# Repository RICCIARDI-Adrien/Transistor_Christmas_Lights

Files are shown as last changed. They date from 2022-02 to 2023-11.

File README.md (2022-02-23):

# Transistor Christmas Lights

A really simple blinking Christmas lights using only bipolar transistors for its logic.

## Circuits

The board is made of 2 separate circuits : the motherboard and the light.  
The motherboard circuit holds the logic while the light circuit contains the leds.  
The light circuit should be manufactured in about 20 copies.

## Circuit simulation

The circuit concept is simulated with [Logisim Evolution](https://github.com/logisim-evolution/logisim-evolution) version 3.7.2, the Logisim file is located [here](Motherboard/Simulation/Logisim_Simulation.circ).  
I tried to keep the gates count as low as possible and I tried to select gates that also minimize the transistors count.  
The Logicim file gathers some different tests for the same logic block, all these tests are still present in the file if needed.

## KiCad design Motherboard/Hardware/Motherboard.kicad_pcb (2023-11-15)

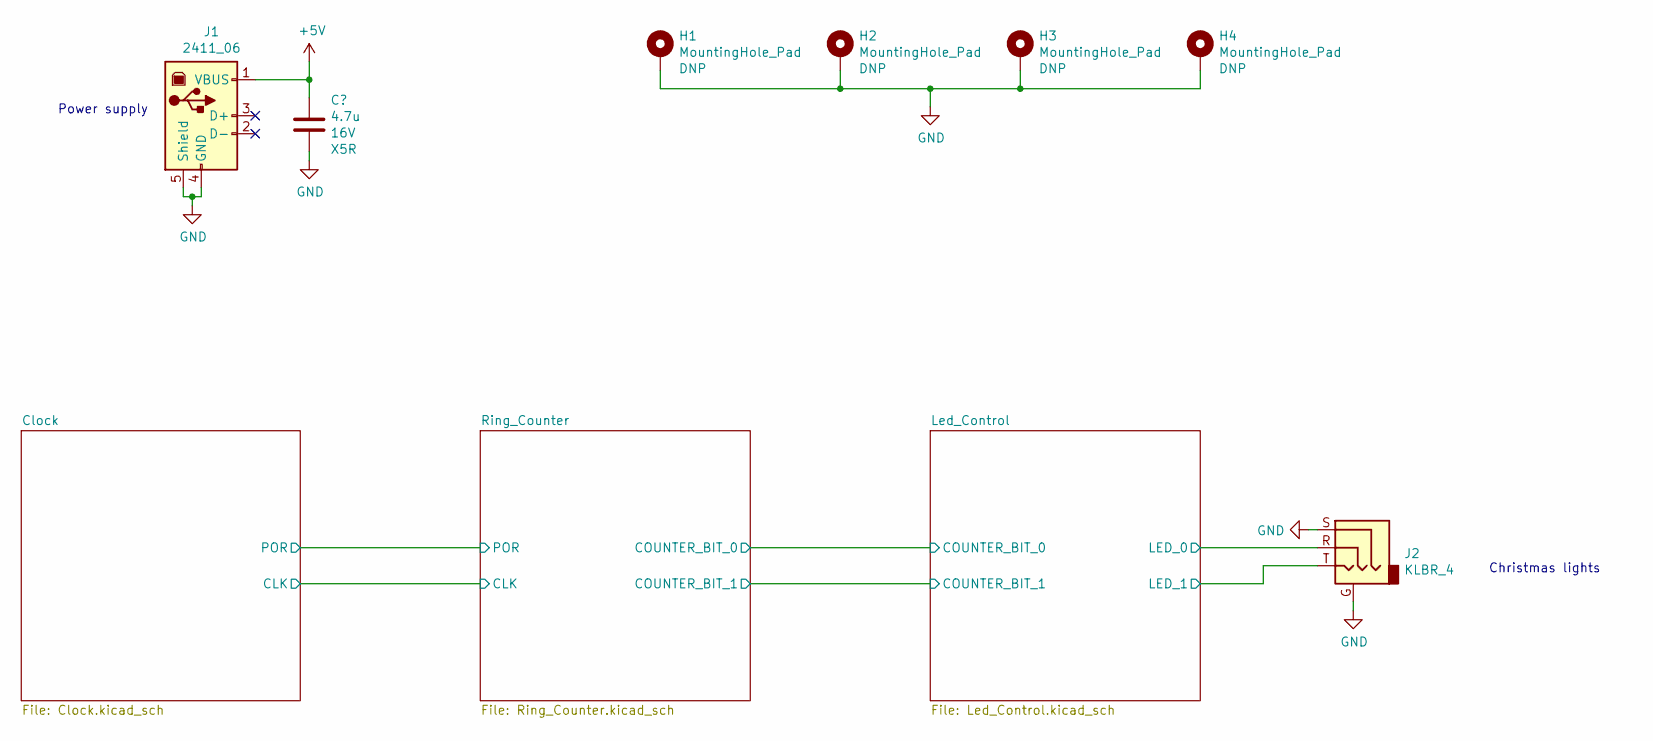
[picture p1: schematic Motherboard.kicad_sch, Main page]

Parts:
C1: 4.7u; C_0805_2012Metric_Pad1.18x1.45mm_HandSolder; PartNumber CL21A475KOFNNNE
H1, H2, H3, H4: MountingHole_Pad; MountingHole_4.5mm_Pad
J1: 2411_06; USB_B_OST_USB-B1HSxx_Horizontal; PartNumber 2411_06
J2: KLBR_4; PartNumber KLBR_4

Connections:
/Led_Control/LED_0: J2.R; also elsewhere on the board
/Led_Control/LED_1: J2.T; also elsewhere on the board
GND: C1.2, H1.1, H2.1, H3.1, H4.1, J1.4 (GND), J1.5 (Shield), J2.G, J2.S; also elsewhere on the board

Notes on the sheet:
Power supply
Christmas lights

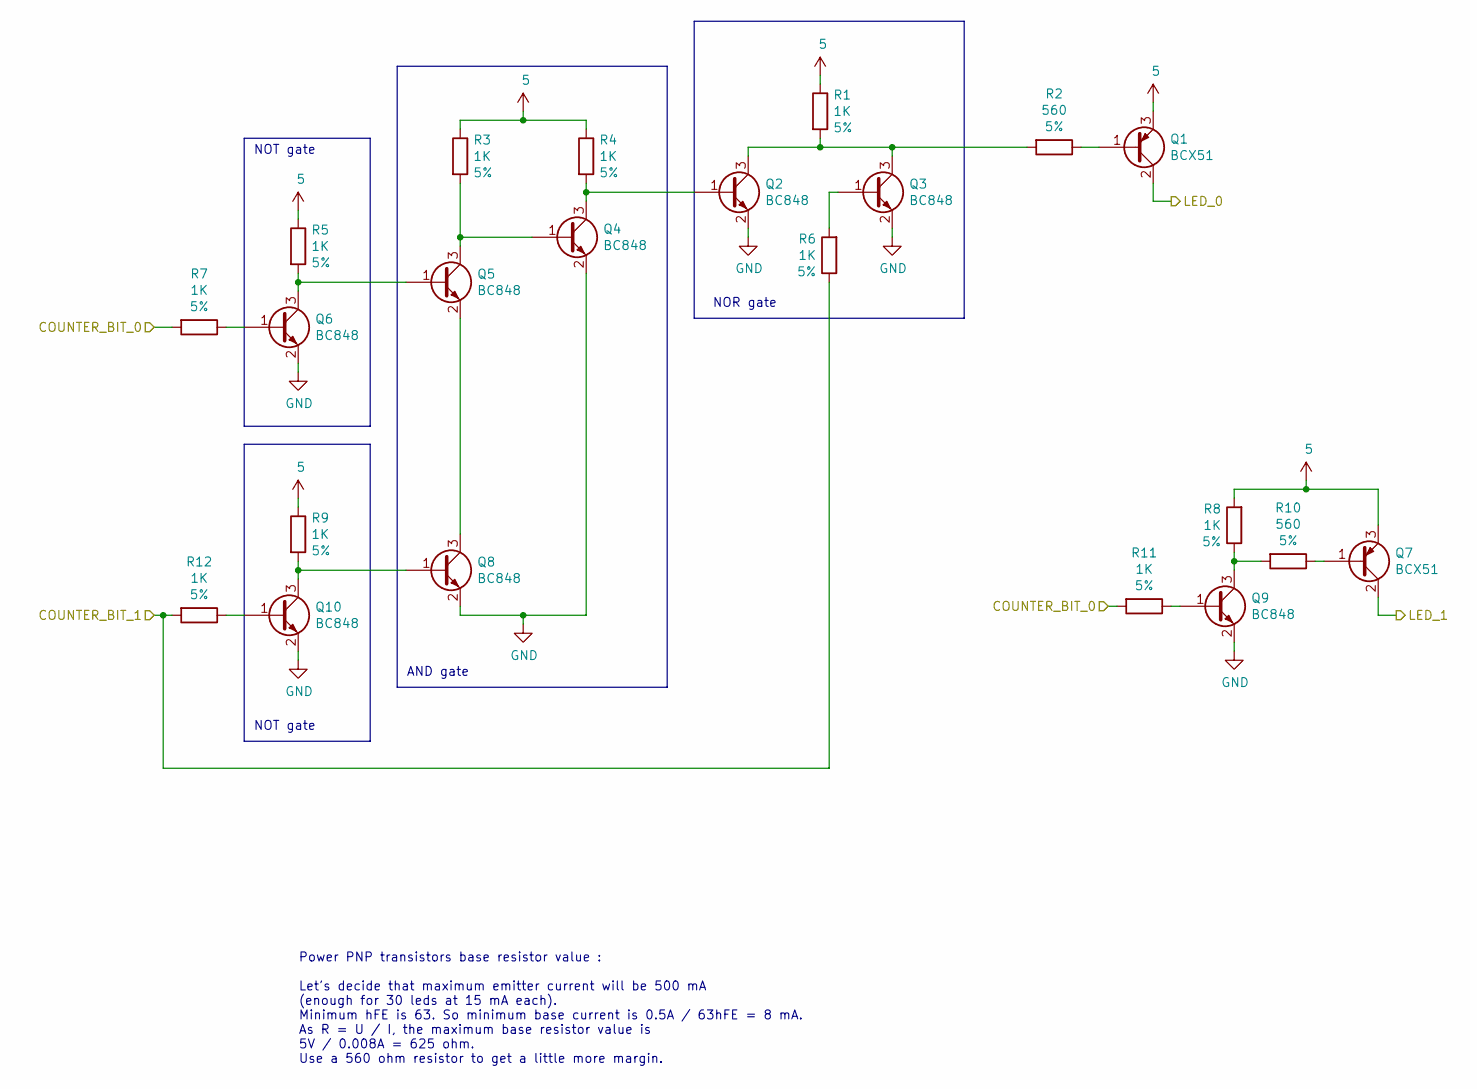
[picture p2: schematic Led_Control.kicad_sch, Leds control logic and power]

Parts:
Q1, Q7: BCX51; SOT-89-3; PartNumber BCX51,115
Q2, Q3, Q4, Q5, Q6, Q8, Q9, Q10: BC848; SOT-23
R1, R3, R4, R5, R6, R7, R8, R9, R11, R12: 1K; R_0603_1608Metric_Pad0.98x0.95mm_HandSolder
R2, R10: 560; R_0603_1608Metric_Pad0.98x0.95mm_HandSolder

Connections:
/Led_Control/COUNTER_BIT_0: R7.2, R11.2; also elsewhere on the board
/Led_Control/COUNTER_BIT_1: R6.1, R12.2; also elsewhere on the board
/Led_Control/LED_0: Q1.2 (C); also elsewhere on the board
/Led_Control/LED_1: Q7.2 (C); also elsewhere on the board
GND: Q2.2 (E), Q3.2 (E), Q4.2 (E), Q6.2 (E), Q8.2 (E), Q9.2 (E), Q10.2 (E); also elsewhere on the board
unnamed: Q1.1 (B), R2.1
unnamed: Q2.1 (B), Q4.3 (C), R4.2
unnamed: Q2.3 (C), Q3.3 (C), R1.2, R2.2
unnamed: Q3.1 (B), R6.2
unnamed: Q4.1 (B), Q5.3 (C), R3.2
unnamed: Q5.1 (B), Q6.3 (C), R5.2
unnamed: Q5.2 (E), Q8.3 (C)
unnamed: Q6.1 (B), R7.1
unnamed: Q7.1 (B), R10.1
unnamed: Q9.1 (B), R11.1
unnamed: Q9.3 (C), R8.1, R10.2
unnamed: Q10.1 (B), R12.1
unnamed: Q8.1 (B), Q10.3 (C), R9.2

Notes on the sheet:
NOT gate
Power PNP transistors base resistor value : Let's decide that maximum emitter current will be 500 mA (enough for 30 leds at 15 mA each). Minimum hFE is 63. So minimum base current is 0.5A / 63hFE = 8 mA. As R = U / I, the maximum base resistor value is 5V / 0.008A = 625 ohm. Use a 560 ohm resistor 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
NOR gate
AND gate

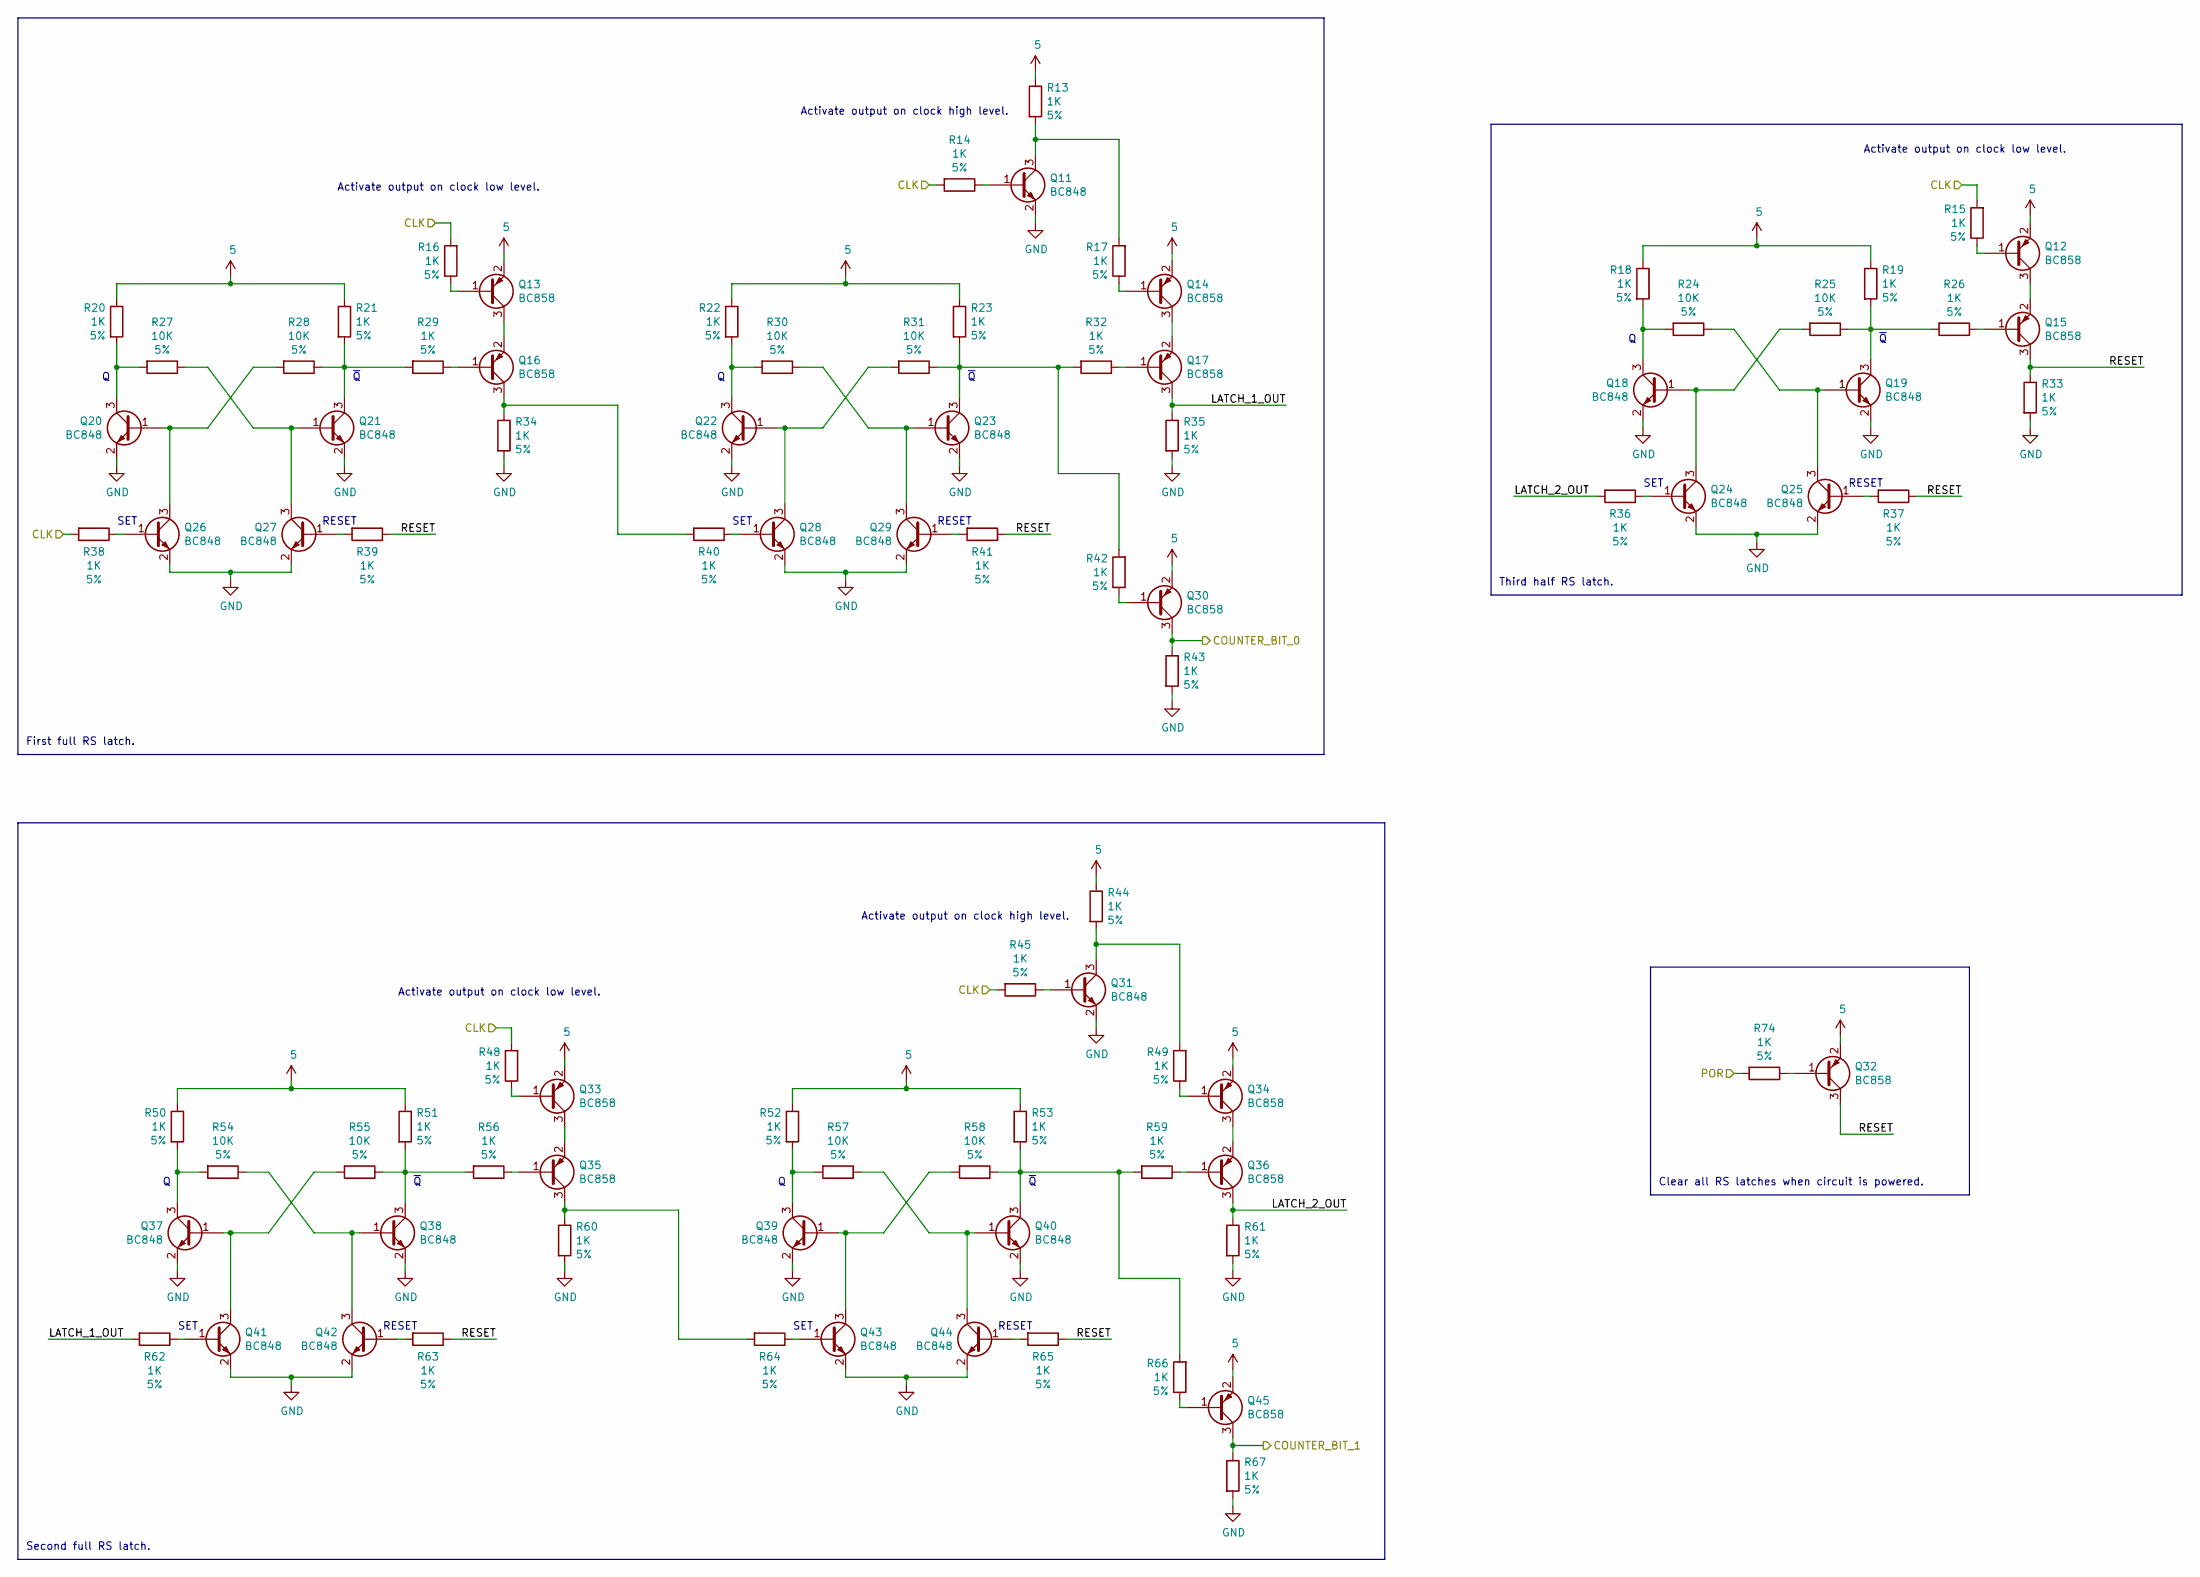
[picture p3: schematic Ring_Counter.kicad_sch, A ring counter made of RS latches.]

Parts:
Q11, Q18, Q19, Q20, Q21, Q22, Q23, Q24, Q25, Q26, Q27, Q28, Q29, Q31, Q37, Q38, Q39, Q40, Q41, Q42, Q43, Q44: BC848; SOT-23
Q12, Q13, Q14, Q15, Q16, Q17, Q30, Q32, Q33, Q34, Q35, Q36, Q45: BC858; SOT-23
R13, R14, R15, R16, R17, R18, R19, R20, R21, R22, R23, R26, R29, R32, R33, R34, R35, R36, R37, R38, R39, R40, R41, R42, R43, R44, R45, R48, R49, R50, R51, R52, R53, R56, R59, R60, R61, R62, R63, R64, R65, R66, R67, R74: 1K; R_0603_1608Metric_Pad0.98x0.95mm_HandSolder
R24, R25, R27, R28, R30, R31, R54, R55, R57, R58: 10K; R_0603_1608Metric_Pad0.98x0.95mm_HandSolder

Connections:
/Clock/CLK: R14.2, R15.2, R16.2, R38.2, R45.2, R48.2; also elsewhere on the board
/Clock/POR: R74.2; also elsewhere on the board
/Led_Control/COUNTER_BIT_0: Q30.3 (C), R43.1; also elsewhere on the board
/Led_Control/COUNTER_BIT_1: Q45.3 (C), R67.1; also elsewhere on the board
/Ring_Counter/LATCH_1_OUT: Q17.3 (C), R35.1, R62.2
/Ring_Counter/LATCH_2_OUT: Q36.3 (C), R36.2, R61.1
/Ring_Counter/RESET: Q15.3 (C), Q32.3 (C), R33.1, R37.1, R39.1, R41.1, R63.1, R65.1
GND: Q11.2 (E), Q18.2 (E), Q19.2 (E), Q20.2 (E), Q21.2 (E), Q22.2 (E), Q23.2 (E), Q24.2 (E), Q25.2 (E), Q26.2 (E), Q27.2 (E), Q28.2 (E), Q29.2 (E), Q31.2 (E), Q37.2 (E), Q38.2 (E), Q39.2 (E), Q40.2 (E), Q41.2 (E), Q42.2 (E), Q43.2 (E), Q44.2 (E), R33.2, R34.2, R35.2, R43.2, R60.2, R61.2, R67.2; also elsewhere on the board
unnamed: Q11.1 (B), R14.1
unnamed: Q11.3 (C), R13.2, R17.2
unnamed: Q12.1 (B), R15.1
unnamed: Q12.3 (C), Q15.2 (E)
unnamed: Q13.1 (B), R16.1
unnamed: Q13.3 (C), Q16.2 (E)
unnamed: Q14.1 (B), R17.1
unnamed: Q14.3 (C), Q17.2 (E)
unnamed: Q15.1 (B), R26.1
unnamed: Q16.1 (B), R29.1
unnamed: Q16.3 (C), R34.1, R40.2
unnamed: Q17.1 (B), R32.1
unnamed: Q18.1 (B), Q24.3 (C), R25.2
unnamed: Q18.3 (C), R18.2, R24.2
unnamed: Q19.1 (B), Q25.3 (C), R24.1
unnamed: Q19.3 (C), R19.2, R25.1, R26.2
unnamed: Q20.1 (B), Q26.3 (C), R28.2
unnamed: Q20.3 (C), R20.2, R27.2
unnamed: Q21.1 (B), Q27.3 (C), R27.1
unnamed: Q21.3 (C), R21.2, R28.1, R29.2
unnamed: Q22.1 (B), Q28.3 (C), R31.2
unnamed: Q22.3 (C), R22.2, R30.2
unnamed: Q23.1 (B), Q29.3 (C), R30.1
unnamed: Q23.3 (C), R23.2, R31.1, R32.2, R42.2
unnamed: Q24.1 (B), R36.1
unnamed: Q25.1 (B), R37.2
unnamed: Q26.1 (B), R38.1
unnamed: Q27.1 (B), R39.2
unnamed: Q28.1 (B), R40.1
unnamed: Q29.1 (B), R41.2
unnamed: Q30.1 (B), R42.1
unnamed: Q31.1 (B), R45.1
unnamed: Q31.3 (C), R44.2, R49.2
unnamed: Q32.1 (B), R74.1
unnamed: Q33.1 (B), R48.1
unnamed: Q33.3 (C), Q35.2 (E)
unnamed: Q34.1 (B), R49.1
unnamed: Q34.3 (C), Q36.2 (E)
unnamed: Q35.1 (B), R56.1
unnamed: Q35.3 (C), R60.1, R64.2
unnamed: Q36.1 (B), R59.1
unnamed: Q37.1 (B), Q41.3 (C), R55.2
unnamed: Q37.3 (C), R50.2, R54.2
unnamed: Q38.1 (B), Q42.3 (C), R54.1
unnamed: Q38.3 (C), R51.2, R55.1, R56.2
unnamed: Q39.1 (B), Q43.3 (C), R58.2
unnamed: Q39.3 (C), R52.2, R57.2
unnamed: Q40.1 (B), Q44.3 (C), R57.1
unnamed: Q40.3 (C), R53.2, R58.1, R59.2, R66.2
unnamed: Q41.1 (B), R62.1
unnamed: Q42.1 (B), R63.2
unnamed: Q43.1 (B), R64.1
unnamed: Q44.1 (B), R65.2
unnamed: Q45.1 (B), R66.1

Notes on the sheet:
Third half RS latch.
SET
~{Q}
RESET
Clear all RS latches when circuit is powered.
Activate output on clock low level.
First full RS latch.
Activate output on clock high level.
Second full RS latch.

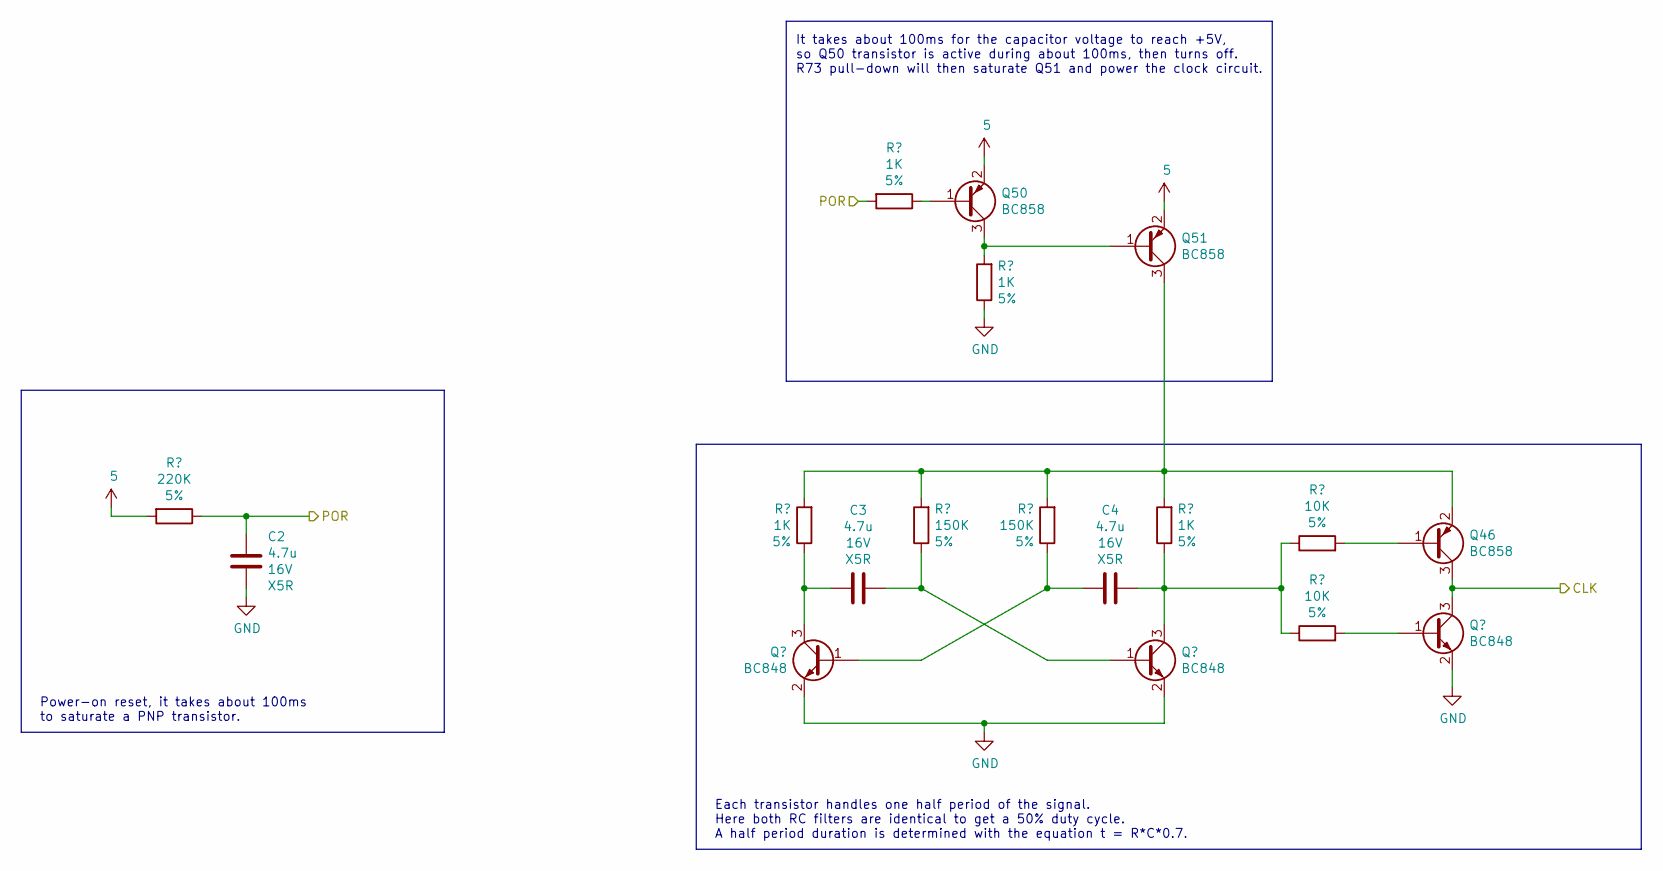
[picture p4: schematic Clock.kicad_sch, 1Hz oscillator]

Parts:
C2, C3, C4: 4.7u; C_0805_2012Metric_Pad1.18x1.45mm_HandSolder; PartNumber CL21A475KOFNNNE
Q46, Q50, Q51: BC858; SOT-23
Q47, Q48, Q49: BC848; SOT-23
R46: 220K; R_0603_1608Metric_Pad0.98x0.95mm_HandSolder
R47, R68, R71, R73: 1K; R_0603_1608Metric_Pad0.98x0.95mm_HandSolder
R69, R70: 150K; R_0603_1608Metric_Pad0.98x0.95mm_HandSolder
R72, R75: 10K; R_0603_1608Metric_Pad0.98x0.95mm_HandSolder

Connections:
/Clock/CLK: Q46.3 (C), Q47.3 (C); also elsewhere on the board
/Clock/POR: C2.1, R46.1, R47.2; also elsewhere on the board
GND: C2.2, Q47.2 (E), Q48.2 (E), Q49.2 (E), R73.1; also elsewhere on the board
unnamed: Q46.1 (B), R72.2
unnamed: Q46.2 (E), Q51.3 (C), R68.2, R69.2, R70.2, R71.2
unnamed: Q47.1 (B), R75.2
unnamed: C4.2, Q48.1 (B), R70.1
unnamed: C3.2, Q48.3 (C), R68.1
unnamed: C3.1, Q49.1 (B), R69.1
unnamed: C4.1, Q49.3 (C), R71.1, R72.1, R75.1
unnamed: Q50.1 (B), R47.1
unnamed: Q50.3 (C), Q51.1 (B), R73.2

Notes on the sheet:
It takes about 100ms for the capacitor voltage to reach +5V, so Q50 transistor is active during about 100ms, then turns off. R73 pull-down will then saturate Q51 and power the clock circuit.
Each transistor handles one half period of the signal. Here both RC filters are identical to get a 50% duty cycle. A half period duration is determined with the equation t = R*C*0.7.
Power-on reset, it takes about 100ms to saturate a PNP transistor.

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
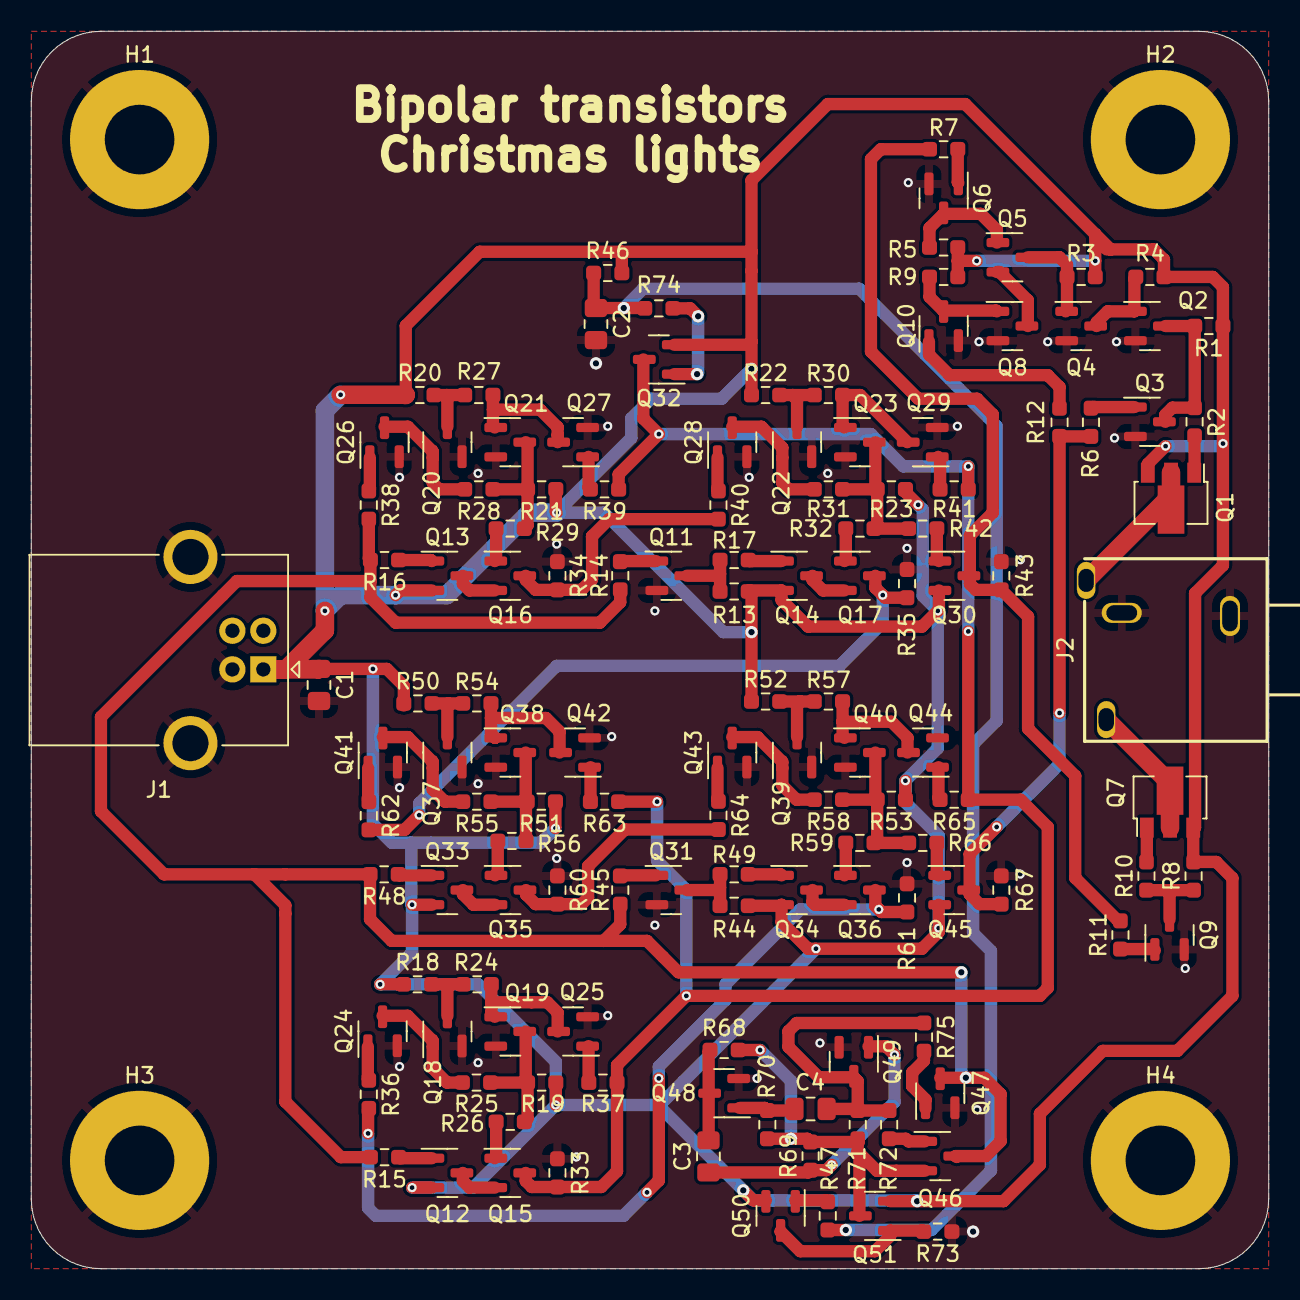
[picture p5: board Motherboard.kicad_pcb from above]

Board: 2 copper layers, 80.0 x 80.0 mm, 136 parts (0 on the bottom side), 87 nets.

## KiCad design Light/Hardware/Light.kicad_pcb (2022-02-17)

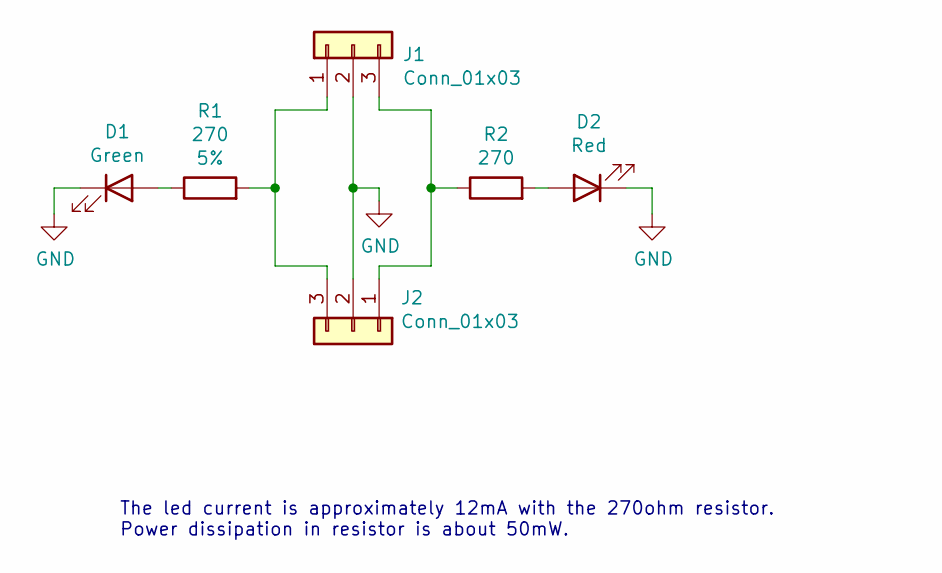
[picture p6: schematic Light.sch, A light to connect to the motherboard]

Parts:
D1: Green; LED_D5.0mm_Horizontal_O1.27mm_Z3.0mm
D2: Red; LED_D5.0mm_Horizontal_O1.27mm_Z3.0mm
J1, J2: Conn_01x03; PinHeader_1x03_P2.54mm_Horizontal
R1, R2: 270; R_1206_3216Metric_Pad1.30x1.75mm_HandSolder

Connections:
GND: D1.1 (K), D2.1 (K), J1.2, J2.2
unnamed: D1.2 (A), R1.1
unnamed: D2.2 (A), R2.2
unnamed: J1.1, J2.3, R1.2
unnamed: J1.3, J2.1, R2.1

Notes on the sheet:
The led current is approximately 12mA with the 270ohm resistor. Power dissipation in resistor is about 50mW.

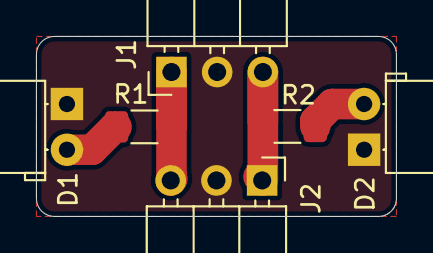
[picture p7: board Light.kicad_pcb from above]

Board: 2 copper layers, 20.0 x 10.0 mm, 6 parts (0 on the bottom side), 5 nets.

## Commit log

2021-12-29 Added a circuit concept simulation based on logic gates.
2021-12-30 Created the PCB KiCad project. Added a test circuit to setup the circuit SPICE simulation.
    [Transistor_Christmas_Lights.kicad_pcb, Transistor_Christmas_Lights.sch]
2022-01-01 Added led control logic to schematic. The second led power transistor will be added later.
    [Led_Control.sch, Transistor_Christmas_Lights.sch]
2022-01-04 Added a ring counter circuit made only of RS latches to the Logicim simulation.
2022-01-04 Removed an unused RS latch in the Logisim ring counter circuit.
2022-01-04 Added the ring counter to the schematic.
    [Led_Control.sch, Ring_Counter.sch, Transistor_Christmas_Lights.sch]
2022-01-20 Improved ring counter RS latches output with better signal quality and less transistors count.
    [Led_Control.sch, Ring_Counter.sch, Transistor_Christmas_Lights.sch]
2022-01-20 Added second led logic and power transistor, also added BC858 SPICE model.
    [Led_Control.sch, Ring_Counter.sch, Transistor_Christmas_Lights.sch]
2022-02-16 Added RS latches power-on reset.
    [Led_Control.sch, Ring_Counter.sch]
2022-02-16 Added oscillator to schematic.
    [Clock.sch, Led_Control.sch, Ring_Counter.sch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]
2022-02-16 Moved motherboard hardware design to a dedicated directory to make room for the christmas lights board.
    [Clock.sch, Led_Control.sch, Ring_Counter.sch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]
2022-02-16 Added light board schematic.
    [Light.kicad_pcb, Light.sch]
2022-02-17 Added light board PCB.
    [Light.kicad_pcb]
2022-02-17 Renamed motherboard KiCad project for more coherency.
    [Motherboard.kicad_pcb, Motherboard.sch]
2022-02-17 Added power supply and Christmas lights connectors to motherboard schematic.
    [Led_Control.sch, Motherboard.sch]
2022-02-17 Renamed all motherboard components so the name are ordered.
    [Clock.sch, Led_Control.sch, Motherboard.sch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]
2022-02-21 Placed most of the components on the PCB.
    [Motherboard.kicad_pcb, Motherboard.sch]
2022-02-21 Adapted KLBR 4 jack socket footprint pins naming to match KiCad default symbol.
    [Motherboard.kicad_pcb]
2022-02-21 Placed all components and mounting holes on PCB.
    [Motherboard.kicad_pcb]
2022-02-21 Routed PCB.
    [Motherboard.kicad_pcb]
2022-02-23 Disabled the motherboard clock circuit power supply while power-on reset delay is running to avoid clocking the RS gates while they are being reset by the power-on reset.
    [Clock.sch, Motherboard.kicad_pcb, Motherboard.sch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]
2022-02-23 Added more component details to the 'light' schematic.
    [Light.sch]
2022-02-23 Added more information about the two circuits to the README.md.
2022-03-16 Fixed clock output push-pull stage in schematic.
    [Clock.sch]
2023-11-15 Updated the motherboard schematic to KiCad 7.
    [Clock.kicad_sch, Clock.sch, Led_Control.kicad_sch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]
2023-11-15 Updated the motherboard PCB to KiCad 7.
    [Clock.kicad_sch, Led_Control.kicad_sch, Motherboard.kicad_pcb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]
2023-11-15 Added the missing courtyard information to the KLBR 4 jack connector footprint and updated the motherboard PCB accordingly.
    [Motherboard.kicad_pcb]
2023-11-15 Added round corners to the motherboard PCB.
    [Motherboard.kicad_pcb]
2023-11-15 Excluded the motherboard connectors and the mounting holes from the simulation.
    [Motherboard.kicad_sch]
